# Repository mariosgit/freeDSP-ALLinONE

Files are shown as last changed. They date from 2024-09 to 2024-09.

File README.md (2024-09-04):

# freeDSP ALLinONE
BOARD STATUS: READY TO BE BUILT

Upgrade of the [freeDSP Classic SMD-B](https://github.com/freeDSP/freeDSP-CLASSIC-SMD-B/blob/master/README.md)

LICENCE: Creative Commons Attribution Share-Alike 4.0 license

https://freedsp.github.io/

[Mouser BOM](https://www.mouser.com/ProjectManager/ProjectDetail.aspx?AccessID=5c5f7288d7)

## mb/improvements branch

 * PowerDown muting, implemented with one 7414 gate and a Pot. The Pot must be fully turned up (cw) and then down until the mute LED turns of. This determines the Vin voltage where the shutdown occures, it should be slightly below the supply voltage but higher then 5V because @5V the Amps will go into power fail and that will hard click. [simulation](https://www.falstad.com/circuit/circuitjs.html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)
 * One of the 7414 was redundand and has been removed.
 * One of the clip adjust pots was redundand and has been removed.
 * 5V Arduino port was removed, use a 3.3 V device, i2C on the freedsp and adau headers.
 * Added a MCP23008 to read status and provide mute and spdif switching control. Can be left out.
 * I had problems with the ADAU onboard voltage regulator, replaced it with a linear regulator. (dropout is 1.2V should be ok to run @ 3.3V) Anyway increased the switched reg to 5V and the 3.3V line runs on another 1117.
 * Ferritbead before the AMP chips is wrong, AMPs are now powered by VIN.
 * Removed Power input from USBi port.
 * JumperWire and solder enforceable power traces between amps and power terminal
 * break out gain config pins - add 1k resistors r49 r50 as needed.

##### CanDo ?

 * Replace CS8422 QFPpamp / Outdated. But it's the only one with integrated SRC :( 
 * Replace 1206 parts with std 603 parts.
 * Use a power management/supervisor chipo for mute ? 
   * TPS3840PH49DBVR ? ActHigh not adjustable, max 12v
   * TL7700 - active low
   * TPS38 - availables are active low.
   * TL7733 - max 20V, act low+high
   * aaahhh

## About

The freeDSP is an open-source digital signal processor family for the do-it-yourself community. The applications range from active loudspeaker concepts (digital crossovers, bass enhancement, ...) and room equalization over advanced musical effect processors to car audio signal processing. 

The _freeDSP ALLinONE_ is an all-in-one version of the original _freeDSP Classic SMD-B_ with a few improvements, upgrades and changes.
It features four amplified analog outputs as well as S/PDIF in- and output (optical and RCA).
This board has been designed using the Cross-Platform Open Source Tool [KiCad](http://kicad.org/).

More informations kann be found on the [freeDSP website](http://freedsp.cc)

You can find a PDF version of the schematic in the SOURCES folder (LINK)

## Links

[freeDSP Website](http://freedsp.cc)

[Documentation in Google Doc](https://docs.google.com/document/d/1258PKKEvrk1GpFIaAHhm8G6f0HHNBfSL8KVq2VGgUKc/edit?usp=sharing)

[freeDSP Guidelines](https://github.com/freeDSP/WIKI-AND-GENERAL-TOPICS/wiki/freeDSP-Guidelines)

## Git usage

#### How to setup local repository
- Change to your FreeDSP directory
- Clone the repository (including submodule)  
 `git clone --recursive https://github.com/freeDSP/freeDSP-ALLinONE.git` 
- Change to the newly created ALLinONE directory
- Checkout a branch for the library submodule, if you want to modify it as well
  `git submodule foreach 'git checkout 'master''`
- Open the project file in KiCad

#### How to update the local copy
- To update the project  
  `git pull`
- To update the library  
  `git submodule update --remote --merge`

#### To commit and push local changes
- If you modified something in the LIBRARY folder, change to the LIBRARY folder and run  
  `git add .` (Only required if files were added)  
  `git commit -am "Message"`  (Describe what you changed)  
- Change to the project root directory and run
  `git add .` (Only required if files were added)  
  `git commit -am "Message"`  (Describe what you changed)    
- In the project directory run  
  `git push --recurse-submodule=on-demand`  

#### Define alias to make things shorter
- In the project directory run
  `git config alias.supdate 'submodule update --remote --merge'`  
  `git config alias.spush 'push --recurse-submodules=on-demand'`  
- Afterwards you can use `git supdate` to update the submodule and `git spush` to push any commited changes  

#### Other useful commands
- `git status`  
  Shows general information about the current branch, uncommited changes, not yet added new files and more
- `git diff`  
  Shows uncommited changes
- `git reset --hard origin/master`
  Reset all files to the current status of the dev-hs-01 branch on the Github repository  
  **Careful** This deletes all local changes, so make sure all changes you made and you do not want to delete are pushed to the remote repository

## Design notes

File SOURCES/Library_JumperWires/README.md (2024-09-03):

Found there:
https://forum.kicad.info/t/jumper-wires-for-single-double-sided-pcbs/26446

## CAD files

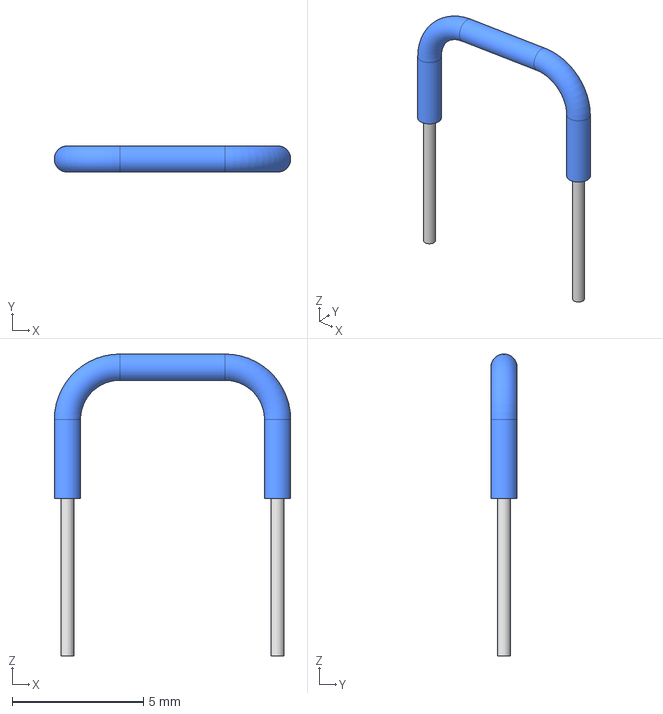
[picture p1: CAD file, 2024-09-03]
SOURCES/Library_JumperWires/Jumper-Wire_8mm_Blue.step
9.00 x 1 x 11.5 mm

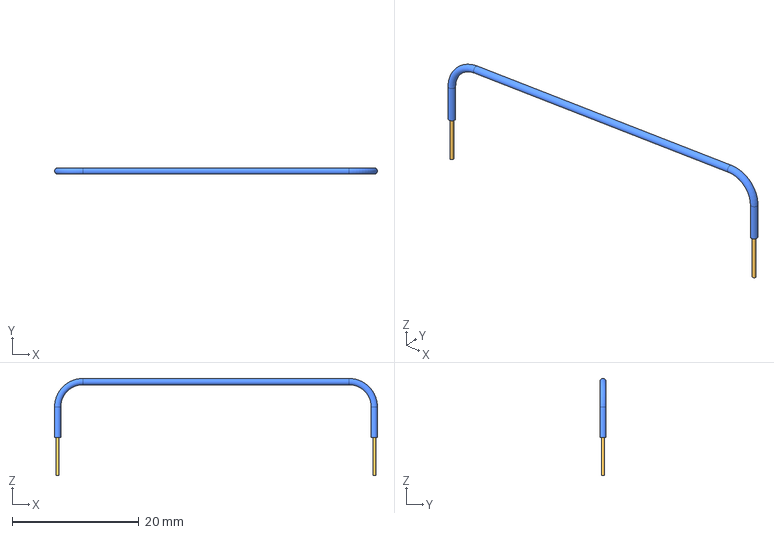
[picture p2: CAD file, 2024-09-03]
SOURCES/Library_JumperWires/Jumper-Wire_50mm_Blue.step
51.0 x 1 x 15.3 mm

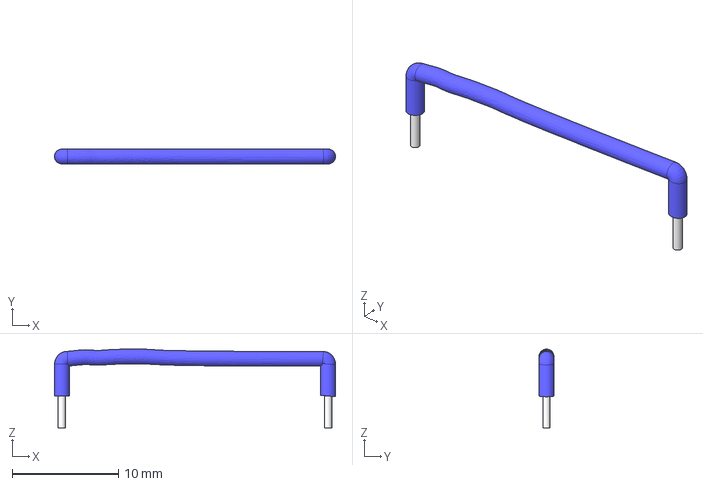
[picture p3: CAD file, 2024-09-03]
SOURCES/Library_JumperWires/Jumper-Wire_25mm_Blue.step
26.4 x 1.40 x 7.41 mm

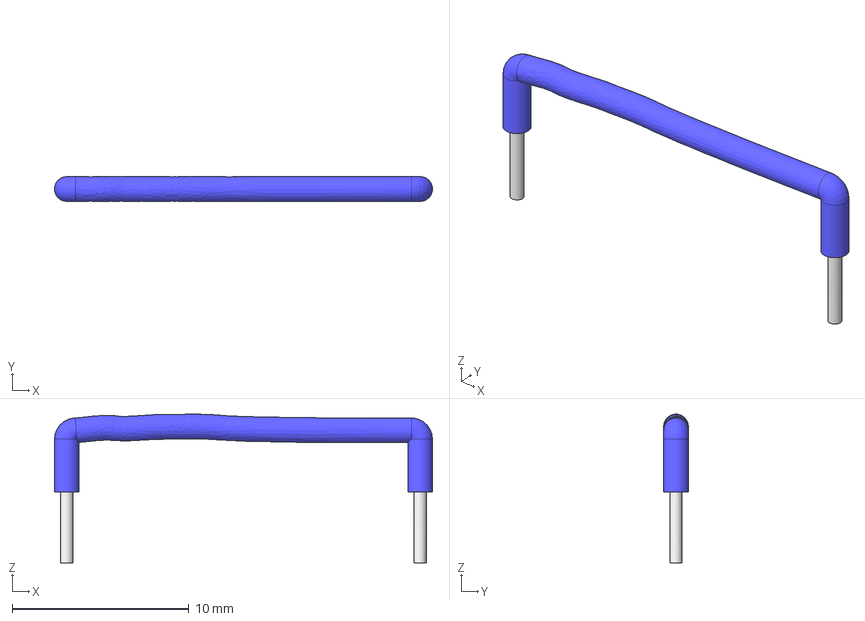
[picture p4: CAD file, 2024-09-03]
SOURCES/Library_JumperWires/Jumper-Wire_20mm_Blue.step
21.4 x 1.40 x 8.41 mm

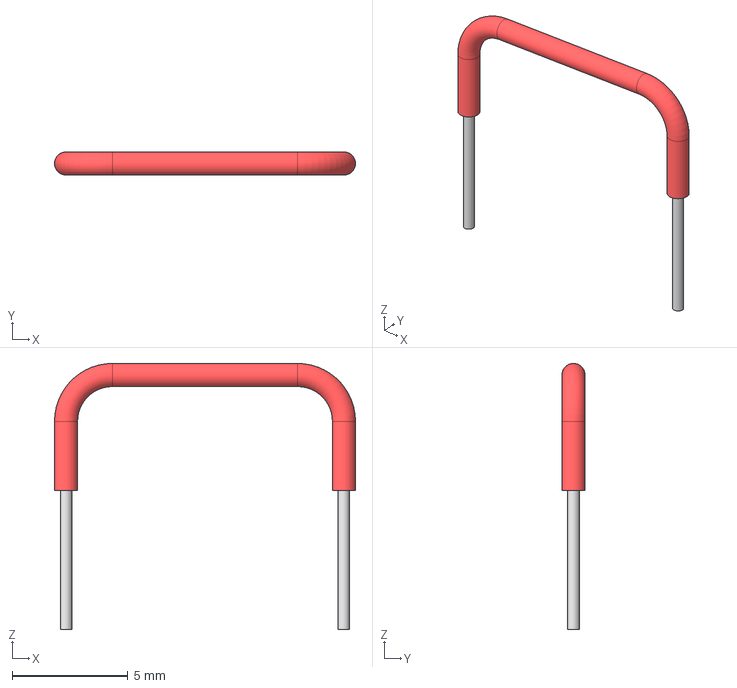
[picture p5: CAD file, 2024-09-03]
SOURCES/Library_JumperWires/Jumper-Wire_12mm_Red.step
13.0 x 1 x 11.5 mm

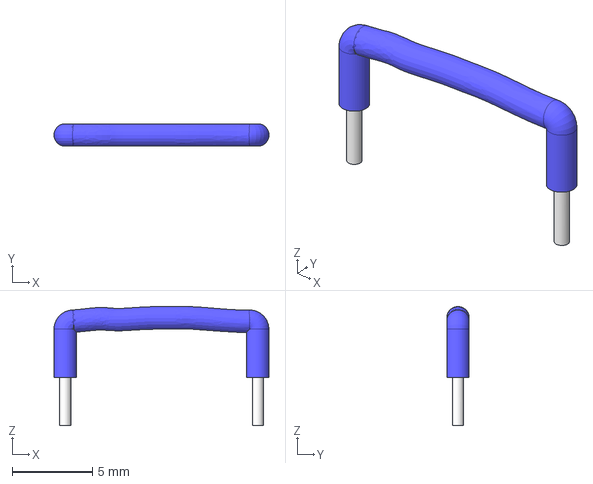
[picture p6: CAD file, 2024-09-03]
SOURCES/Library_JumperWires/Jumper-Wire_12mm_Blue.step
13.4 x 1.40 x 7.42 mm

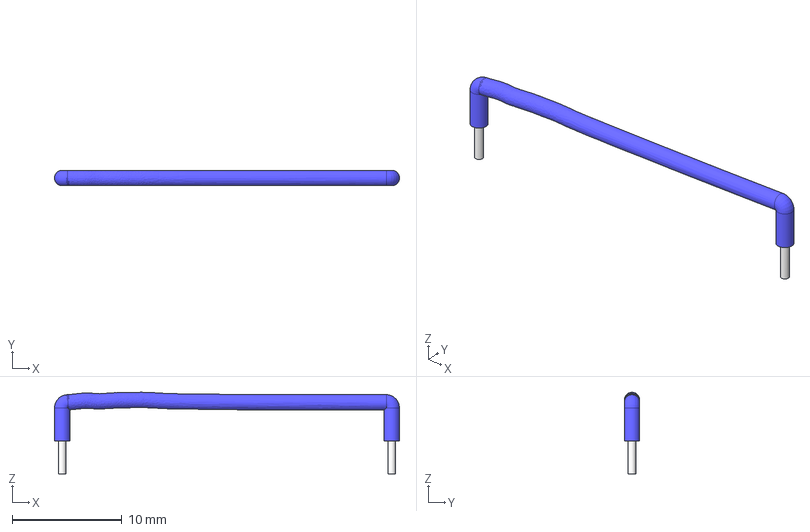
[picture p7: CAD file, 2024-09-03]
SOURCES/Library_JumperWires/Jumper-Wire_30mm_Blue.step
31.4 x 1.40 x 7.42 mm

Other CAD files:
SOURCES/Library_JumperWires/Jumper-Wire_8mm_Red.step

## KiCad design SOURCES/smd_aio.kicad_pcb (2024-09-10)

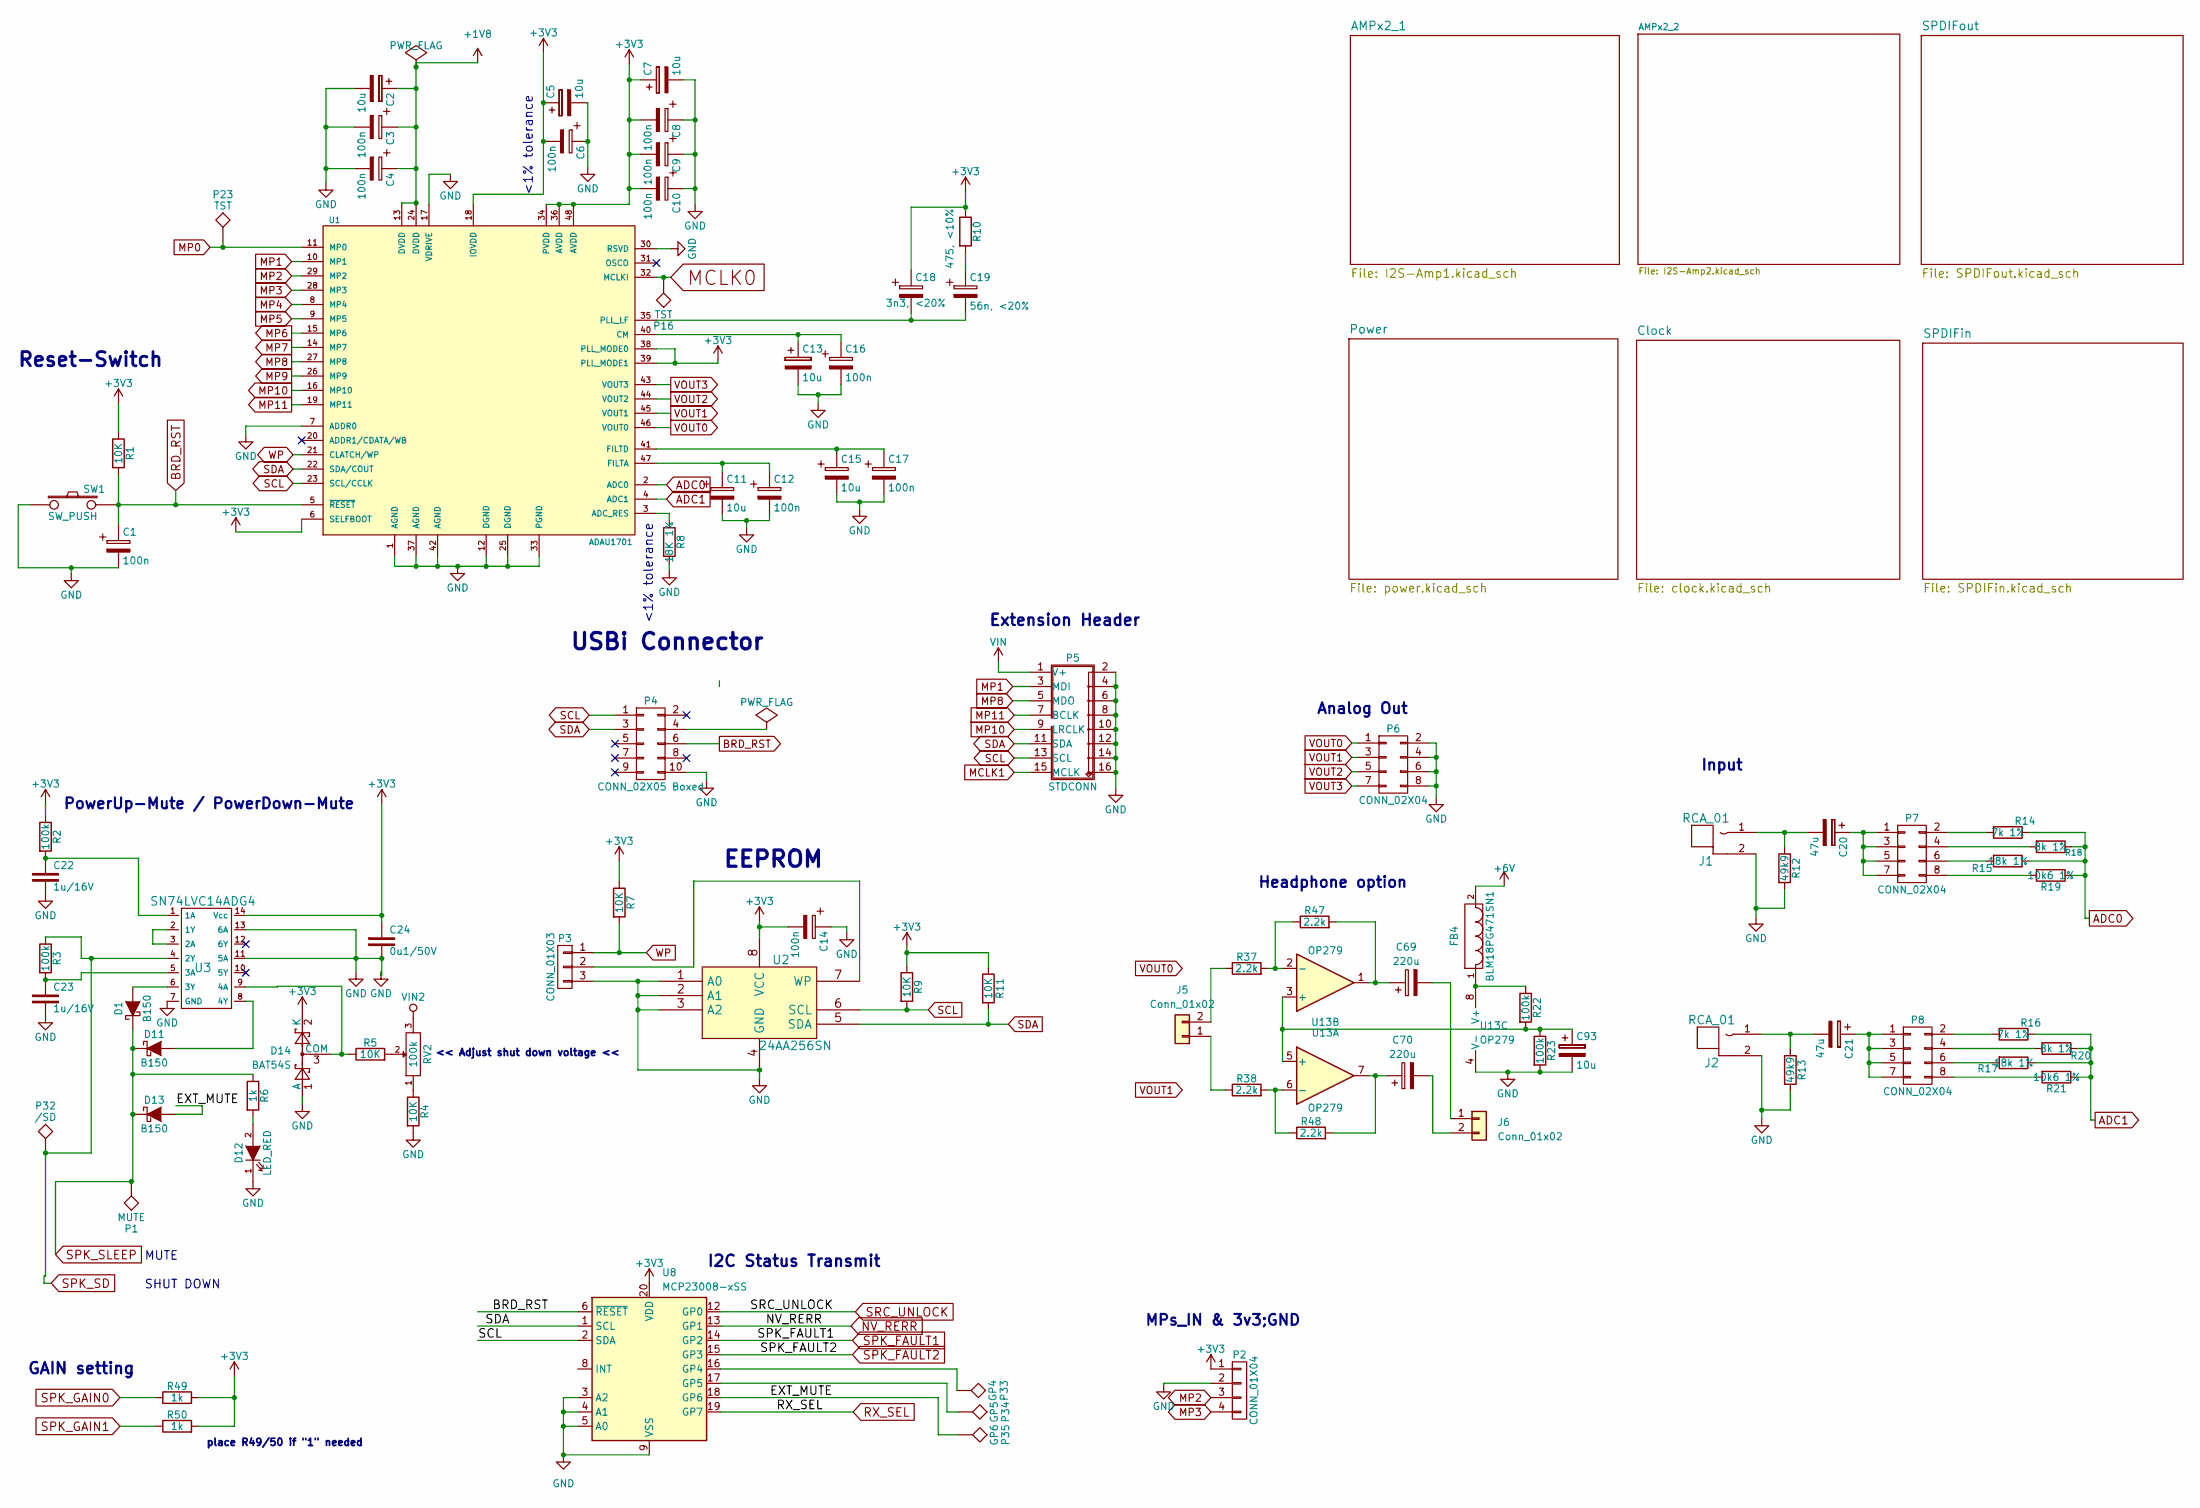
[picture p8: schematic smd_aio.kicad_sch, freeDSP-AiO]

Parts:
C1, C3, C4, C6, C8, C9, C10, C12, C14, C16, C17: 100n; C_1206_HandSoldering
C2: 10u; C_1210_3225Metric_Pad1.33x2.70mm_HandSolder
C5, C7, C13, C93: 10u; C_Radial_D5_L11_P2
C11, C15: 10u; C_1206_HandSoldering
C18: 3n3, <20%; C_1206_HandSoldering
C19: 56n, <20%; C_1206_HandSoldering
C20, C21: 47u; C_Radial_D5_L11_P2
C22, C23: 1u/16V; C_1206_HandSoldering
C24: 0u1/50V; C_1206_HandSoldering
C69, C70: 220u; CP_Elec_6.3x5.9
D1, D11, D13: B150; SMA
D12: LED_RED; R_1206_HandSoldering
D14: BAT54S; SOT-23
FB4: BLM18PG471SN1; R_0603_HandSoldering
J1, J2: RCA_01; RCA_RCJ-01x
J5, J6: Conn_01x02; PinHeader_1x02_P2.54mm_Vertical
P1: MUTE; Measurement_Point_Round-SMD-Pad_Small
P2: CONN_01X04; Pin_Header_Straight_1x04
P3: CONN_01X03; Pin_Header_Straight_1x03
P4: CONN_02X05 Boxed; IDC_Header_Straight_10pins
P5: STDCONN; IDC_Header_Straight_16pins
P6, P7, P8: CONN_02X04; Pin_Header_Straight_2x04
P16, P23: TST; Measurement_Point_Round-SMD-Pad_Small
P32: /SD; Measurement_Point_Round-SMD-Pad_Small
P33: GP4; Measurement_Point_Round-SMD-Pad_Small
P34: GP5; Measurement_Point_Round-SMD-Pad_Small
P35: GP6; Measurement_Point_Round-SMD-Pad_Small
R1, R4, R5, R7, R9, R11: 10K; R_1206_HandSoldering
R2, R3: 100k; R_1206_HandSoldering
R6: 1k; R_1206_HandSoldering
R8: 18K 1%; R_1206_HandSoldering
R10: 475, <10%; R_1206_HandSoldering
R12, R13: 49k9; R_1206_HandSoldering
R14, R16: 7k 1%; R_1206_HandSoldering
R15, R17: 18k 1%; R_1206_HandSoldering
R18, R20: 8k 1%; R_1206_HandSoldering
R19, R21: 10k6 1%; R_1206_HandSoldering
R22, R23: 100k; R_0603_HandSoldering
R37, R38, R47, R48: 2.2k; R_0603_HandSoldering
R49, R50: 1k; R_0603_1608Metric_Pad0.98x0.95mm_HandSolder
RV2: 100k; M64Z104KB40
SW1: SW_PUSH; SW_PUSH_6mm
U1: ADAU1701; LQFP-48_7x7mm_Pitch0.5mm
U2: 24AA256SN; SOIC-8_3.9x4.9mm_Pitch1.27mm
U3: SN74LVC14ADG4; SOIC-14_3.9x8.7mm_Pitch1.27mm
U8: MCP23008-xSS; SSOP-20_5.3x7.2mm_P0.65mm
U13: OP279; SO-8_3.9x4.9mm_P1.27mm

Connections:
+1V8: C2.1, C3.1, C4.1, U1.13 (DVDD), U1.24 (DVDD); also elsewhere on the board
+3V3: C5.1, C6.2, C7.1, C8.2, C9.2, C10.2, C14.2, C18.1, C24.1, D14.2 (K), P2.1, R1.1, R2.1, R7.1, R9.1, R10.1, R11.1, R49.2, R50.2, U1.6 (SELFBOOT), U1.18 (IOVDD), U1.34 (PVDD), U1.36 (AVDD), U1.38 (PLL_MODE0), U1.39 (PLL_MODE1), U1.48 (AVDD), U2.8 (VCC), U3.14 (Vcc), U8.20 (VDD); also elsewhere on the board
+6V: FB4.2; also elsewhere on the board
/EXT_MUTE: D13.2 (A), P35.1, U8.18 (GP6)
ADC0: R14.1, R15.1, R18.1, R19.1, U1.2 (ADC0)
ADC1: R16.1, R17.1, R20.1, R21.1, U1.4 (ADC1)
BRD_RST: C1.1, P4.6, R1.2, SW1.2, U1.5 (~RESET), U8.6 (~RESET); also elsewhere on the board
GND: C1.2, C2.2, C3.2, C4.2, C5.2, C6.1, C7.2, C8.1, C9.1, C10.1, C11.2, C12.2, C13.2, C14.1, C15.2, C16.2, C17.2, C22.2, C23.2, C24.2, C93.2, D12.1 (K), D14.1 (A), J1.2 (GND), J2.2 (GND), P2.2, P3.3, P4.10, P5.2 (GND), P5.4 (GND), P5.6 (GND), P5.8 (GND), P5.10 (GND), P5.12 (GND), P5.14 (GND), P5.16 (GND), P6.2, P6.4, P6.6, P6.8, R4.2, R8.2, R12.2, R13.2, R23.2, SW1.1, U1.1 (AGND), U1.7 (ADDR0), U1.12 (DGND), U1.17 (VDRIVE), U1.25 (DGND), U1.30 (RSVD), U1.33 (PGND), U1.37 (AGND), U1.42 (AGND), U2.1 (A0), U2.2 (A1), U2.3 (A2), U2.4 (GND), U3.7 (GND), U3.11 (5A), U3.13 (6A), U8.3 (A2), U8.4 (A1), U8.5 (A0), U8.9 (VSS), U13.4 (V-); also elsewhere on the board
MCLK0: P16.1, U1.32 (MCLKI); also elsewhere on the board
MCLK1: P5.15 (MCLK); also elsewhere on the board
MP0: P23.1, U1.11 (MP0); also elsewhere on the board
MP1: P5.3 (MDI), U1.10 (MP1)
MP2: P2.3, U1.29 (MP2)
MP3: P2.4, U1.28 (MP3)
MP4: U1.8 (MP4); also elsewhere on the board
MP5: U1.9 (MP5); also elsewhere on the board
MP6: U1.15 (MP6); also elsewhere on the board
MP7: U1.14 (MP7); also elsewhere on the board
MP8: P5.5 (MDO), U1.27 (MP8)
MP9: U1.26 (MP9); also elsewhere on the board
MP10: P5.9 (LRCLK), U1.16 (MP10); also elsewhere on the board
MP11: P5.7 (BCLK), U1.19 (MP11); also elsewhere on the board
NV_RERR: U8.13 (GP1); also elsewhere on the board
unnamed: C19.1, R10.2
unnamed: C69.1, R47.2, U13.1
unnamed: C70.1, R48.2, U13.7
unnamed: D1.2 (A), U3.6 (3Y)
unnamed: D11.2 (A), U3.8 (4Y)
unnamed: D12.2 (A), R6.2
unnamed: D14.3 (COM), R5.1, U3.9 (4A)
unnamed: C20.2, J1.1 (SIG), R12.1
unnamed: C21.2, J2.1 (SIG), R13.1
unnamed: J5.1, R38.1
unnamed: J5.2, R37.1
unnamed: C69.2, J6.1
unnamed: C70.2, J6.2
unnamed: P3.2, U2.7 (WP)
unnamed: C20.1, P7.1, P7.3, P7.5, P7.7
unnamed: P7.2, R14.2
unnamed: P7.4, R18.2
unnamed: P7.6, R15.2
unnamed: P7.8, R19.2
unnamed: C21.1, P8.1, P8.3, P8.5, P8.7
unnamed: P8.2, R16.2
unnamed: P8.4, R20.2
unnamed: P8.6, R17.2
unnamed: P8.8, R21.2
unnamed: R4.1, RV2.1
unnamed: R5.2, RV2.2
unnamed: R8.1, U1.3 (ADC_RES)
unnamed: C13.1, C16.1, U1.40 (CM)
unnamed: C11.1, C12.1, U1.47 (FILTA)
unnamed: C15.1, C17.1, U1.41 (FILTD)
unnamed: C18.2, C19.2, U1.35 (PLL_LF)
unnamed: C22.1, R2.2, U3.1 (1A)
unnamed: U3.2 (1Y), U3.3 (2A)
unnamed: C23.1, R3.2, U3.5 (3A)
unnamed: P33.1, U8.16 (GP4)
unnamed: P34.1, U8.17 (GP5)
unnamed: C93.1, R22.2, R23.1, U13.3 (+), U13.5 (+)
unnamed: R37.2, R47.1, U13.2 (-)
unnamed: R38.2, R48.1, U13.6 (-)
unnamed: FB4.1, R22.1, U13.8 (V+)
RX_SEL: U8.19 (GP7); also elsewhere on the board
SCL: P4.1, P5.13 (SCL), R9.2, U1.23 (SCL/CCLK), U2.6 (SCL), U8.2 (SDA)
SDA: P4.3, P5.11 (SDA), R11.2, U1.22 (SDA/COUT), U2.5 (SDA), U8.1 (SCL)
SPK_FAULT1: U8.14 (GP2); also elsewhere on the board
SPK_FAULT2: U8.15 (GP3); also elsewhere on the board
SPK_GAIN0: R49.1; also elsewhere on the board
SPK_GAIN1: R50.1; also elsewhere on the board
SPK_SD: P32.1, R3.1, U3.4 (2Y); also elsewhere on the board
SPK_SLEEP: D1.1 (K), D11.1 (K), D13.1 (K), P1.1, R6.1; also elsewhere on the board
SRC_UNLOCK: U8.12 (GP0); also elsewhere on the board
VIN: P5.1 (V+); also elsewhere on the board
VIN2: RV2.3; also elsewhere on the board
VOUT0: P6.1, U1.46 (VOUT0)
VOUT1: P6.3, U1.45 (VOUT1)
VOUT2: P6.5, U1.44 (VOUT2)
VOUT3: P6.7, U1.43 (VOUT3)
WP: P3.1, R7.2, U1.21 (CLATCH/WP)

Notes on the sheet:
MPs_IN & 3v3;GND
Headphone option
PowerUp-Mute / PowerDown-Mute
I2C Status Transmit
MUTE
Extension Header
Analog Out
USBi Connector
place R49/50 if "1" needed
GAIN setting
<< Adjust shut down voltage <<
SHUT DOWN
Reset-Switch
Input
<1% tolerance
EEPROM

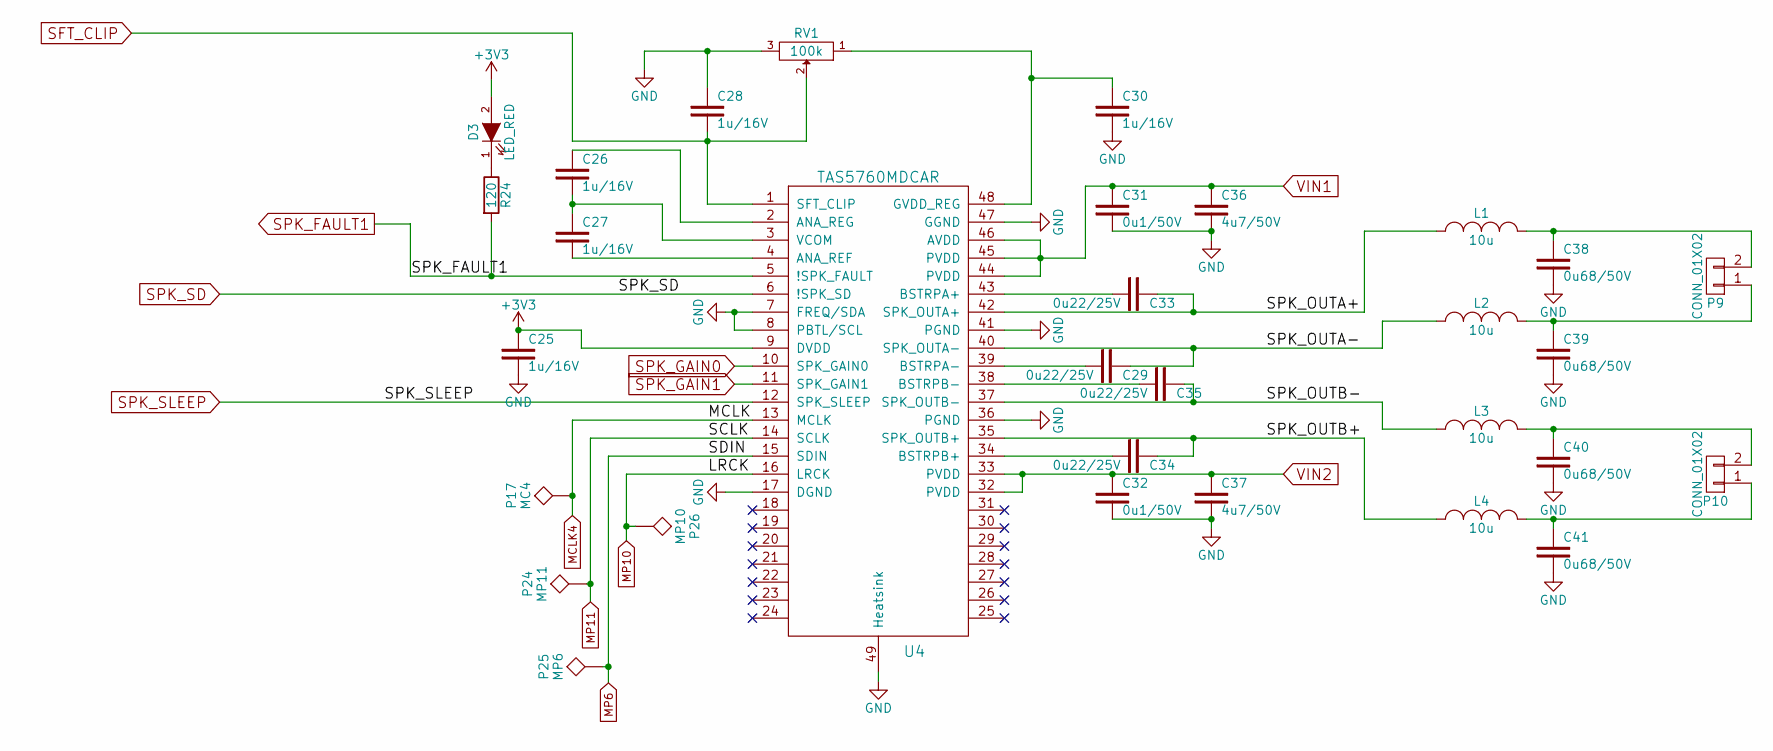
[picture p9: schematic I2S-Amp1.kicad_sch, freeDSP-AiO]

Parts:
C25, C26, C27, C28, C30: 1u/16V; C_1206_HandSoldering
C29, C33, C34, C35: 0u22/25V; C_0805_HandSoldering
C31, C32: 0u1/50V; C_1206_HandSoldering
C36, C37: 4u7/50V; C_1206_HandSoldering
C38, C39, C40, C41: 0u68/50V; C_1206_HandSoldering
D3: LED_RED; R_1206_HandSoldering
L1, L2, L3, L4: 10u; 1D10ASeries
P9, P10: CONN_01X02; RIACON101-2
P17: MC4; Measurement_Point_Round-SMD-Pad_Small
P24: MP11; Measurement_Point_Round-SMD-Pad_Small
P25: MP6; Measurement_Point_Round-SMD-Pad_Small
P26: MP10; Measurement_Point_Round-SMD-Pad_Small
R24: 120; R_1206_HandSoldering
RV1: 100k; M64Z104KB40
U4: TAS5760MDCAR; HTSSOP-48

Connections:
+3V3: C25.1, D3.2 (A), U4.9 (DVDD); also elsewhere on the board
/AMPx2_1/SPK_OUTA+: C33.1, L1.1, U4.42 (SPK_OUTA+)
/AMPx2_1/SPK_OUTA-: C29.1, L2.1, U4.40 (SPK_OUTA-)
/AMPx2_1/SPK_OUTB+: C34.1, L4.1, U4.35 (SPK_OUTB+)
/AMPx2_1/SPK_OUTB-: C35.1, L3.1, U4.37 (SPK_OUTB-)
GND: C25.2, C28.1, C30.2, C31.2, C32.2, C36.2, C37.2, C38.2, C39.2, C40.2, C41.2, RV1.3, U4.7 (FREQ/SDA), U4.8 (PBTL/SCL), U4.17 (DGND), U4.36 (PGND), U4.41 (PGND), U4.47 (GGND), U4.49 (Heatsink); also elsewhere on the board
MCLK4: P17.1, U4.13 (MCLK); also elsewhere on the board
MP6: P25.1, U4.15 (SDIN); also elsewhere on the board
MP10: P26.1, U4.16 (LRCK); also elsewhere on the board
MP11: P24.1, U4.14 (SCLK); also elsewhere on the board
unnamed: D3.1 (K), R24.1
unnamed: C39.1, L2.2, P9.1
unnamed: C38.1, L1.2, P9.2
unnamed: C41.1, L4.2, P10.1
unnamed: C40.1, L3.2, P10.2
unnamed: C27.2, U4.4 (ANA_REF)
unnamed: C26.1, U4.2 (ANA_REG)
unnamed: C33.2, U4.43 (BSTRPA+)
unnamed: C29.2, U4.39 (BSTRPA-)
unnamed: C34.2, U4.34 (BSTRPB+)
unnamed: C35.2, U4.38 (BSTRPB-)
unnamed: C30.1, RV1.1, U4.48 (GVDD_REG)
unnamed: C26.2, C27.1, U4.3 (VCOM)
SFT_CLIP: C28.2, RV1.2, U4.1 (SFT_CLIP); also elsewhere on the board
SPK_FAULT1: R24.2, U4.5 (!SPK_FAULT); also elsewhere on the board
SPK_GAIN0: U4.10 (SPK_GAIN0); also elsewhere on the board
SPK_GAIN1: U4.11 (SPK_GAIN1); also elsewhere on the board
SPK_SD: U4.6 (!SPK_SD); also elsewhere on the board
SPK_SLEEP: U4.12 (SPK_SLEEP); also elsewhere on the board
VIN1: C31.1, C36.1, U4.44 (PVDD), U4.45 (PVDD), U4.46 (AVDD); also elsewhere on the board
VIN2: C32.1, C37.1, U4.32 (PVDD), U4.33 (PVDD); also elsewhere on the board

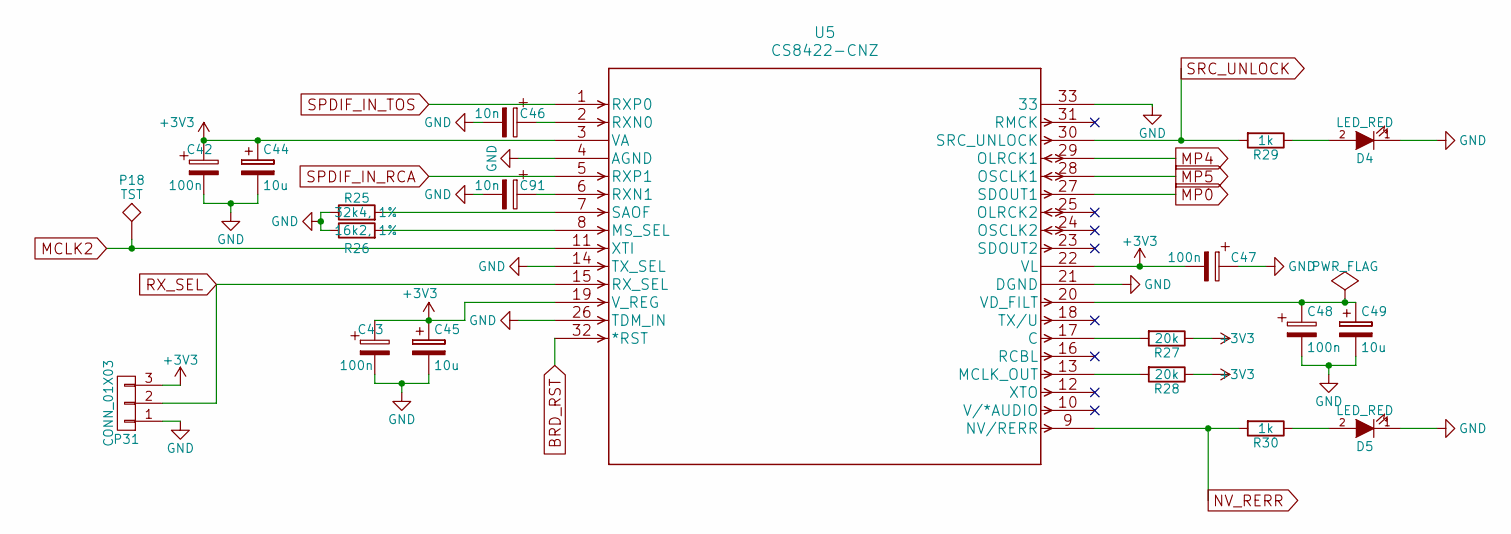
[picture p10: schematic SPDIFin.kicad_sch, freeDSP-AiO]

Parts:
C42, C43, C47, C48: 100n; C_1206_HandSoldering
C44, C45, C49: 10u; C_Radial_D5_L11_P2
C46, C91: 10n; C_1206_HandSoldering
D4, D5: LED_RED; R_1206_HandSoldering
P18: TST; Measurement_Point_Round-SMD-Pad_Small
P31: CONN_01X03; Pin_Header_Straight_1x03
R25: 32k4, 1%; R_1206_HandSoldering
R26: 16k2, 1%; R_1206_HandSoldering
R27, R28: 20k; R_1206_HandSoldering
R29, R30: 1k; R_1206_HandSoldering
U5: CS8422-CNZ

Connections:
+3V3: C42.1, C43.1, C44.1, C45.1, C47.2, P31.3, R27.1, R28.1, U5.3 (VA), U5.19 (V_REG), U5.22 (VL); also elsewhere on the board
BRD_RST: U5.32 (*RST); also elsewhere on the board
GND: C42.2, C43.2, C44.2, C45.2, C46.2, C47.1, C48.2, C49.2, C91.2, D4.1 (K), D5.1 (K), P31.1, R25.1, R26.1, U5.4 (AGND), U5.14 (TX_SEL), U5.21 (DGND), U5.26 (TDM_IN), U5.33; also elsewhere on the board
MCLK2: P18.1, U5.11 (XTI); also elsewhere on the board
MP0: U5.27 (SDOUT1); also elsewhere on the board
MP4: U5.29 (OLRCK1); also elsewhere on the board
MP5: U5.28 (OSCLK1); also elsewhere on the board
NV_RERR: R30.2, U5.9 (NV/RERR); also elsewhere on the board
unnamed: D4.2 (A), R29.1
unnamed: D5.2 (A), R30.1
unnamed: R27.2, U5.17 (C)
unnamed: R28.2, U5.13 (MCLK_OUT)
unnamed: R26.2, U5.8 (MS_SEL)
unnamed: C46.1, U5.2 (RXN0)
unnamed: C91.1, U5.6 (RXN1)
unnamed: R25.2, U5.7 (SAOF)
unnamed: C48.1, C49.1, U5.20 (VD_FILT)
RX_SEL: P31.2, U5.15 (RX_SEL); also elsewhere on the board
SPDIF_IN_RCA: U5.5 (RXP1); also elsewhere on the board
SPDIF_IN_TOS: U5.1 (RXP0); also elsewhere on the board
SRC_UNLOCK: R29.2, U5.30 (SRC_UNLOCK); also elsewhere on the board

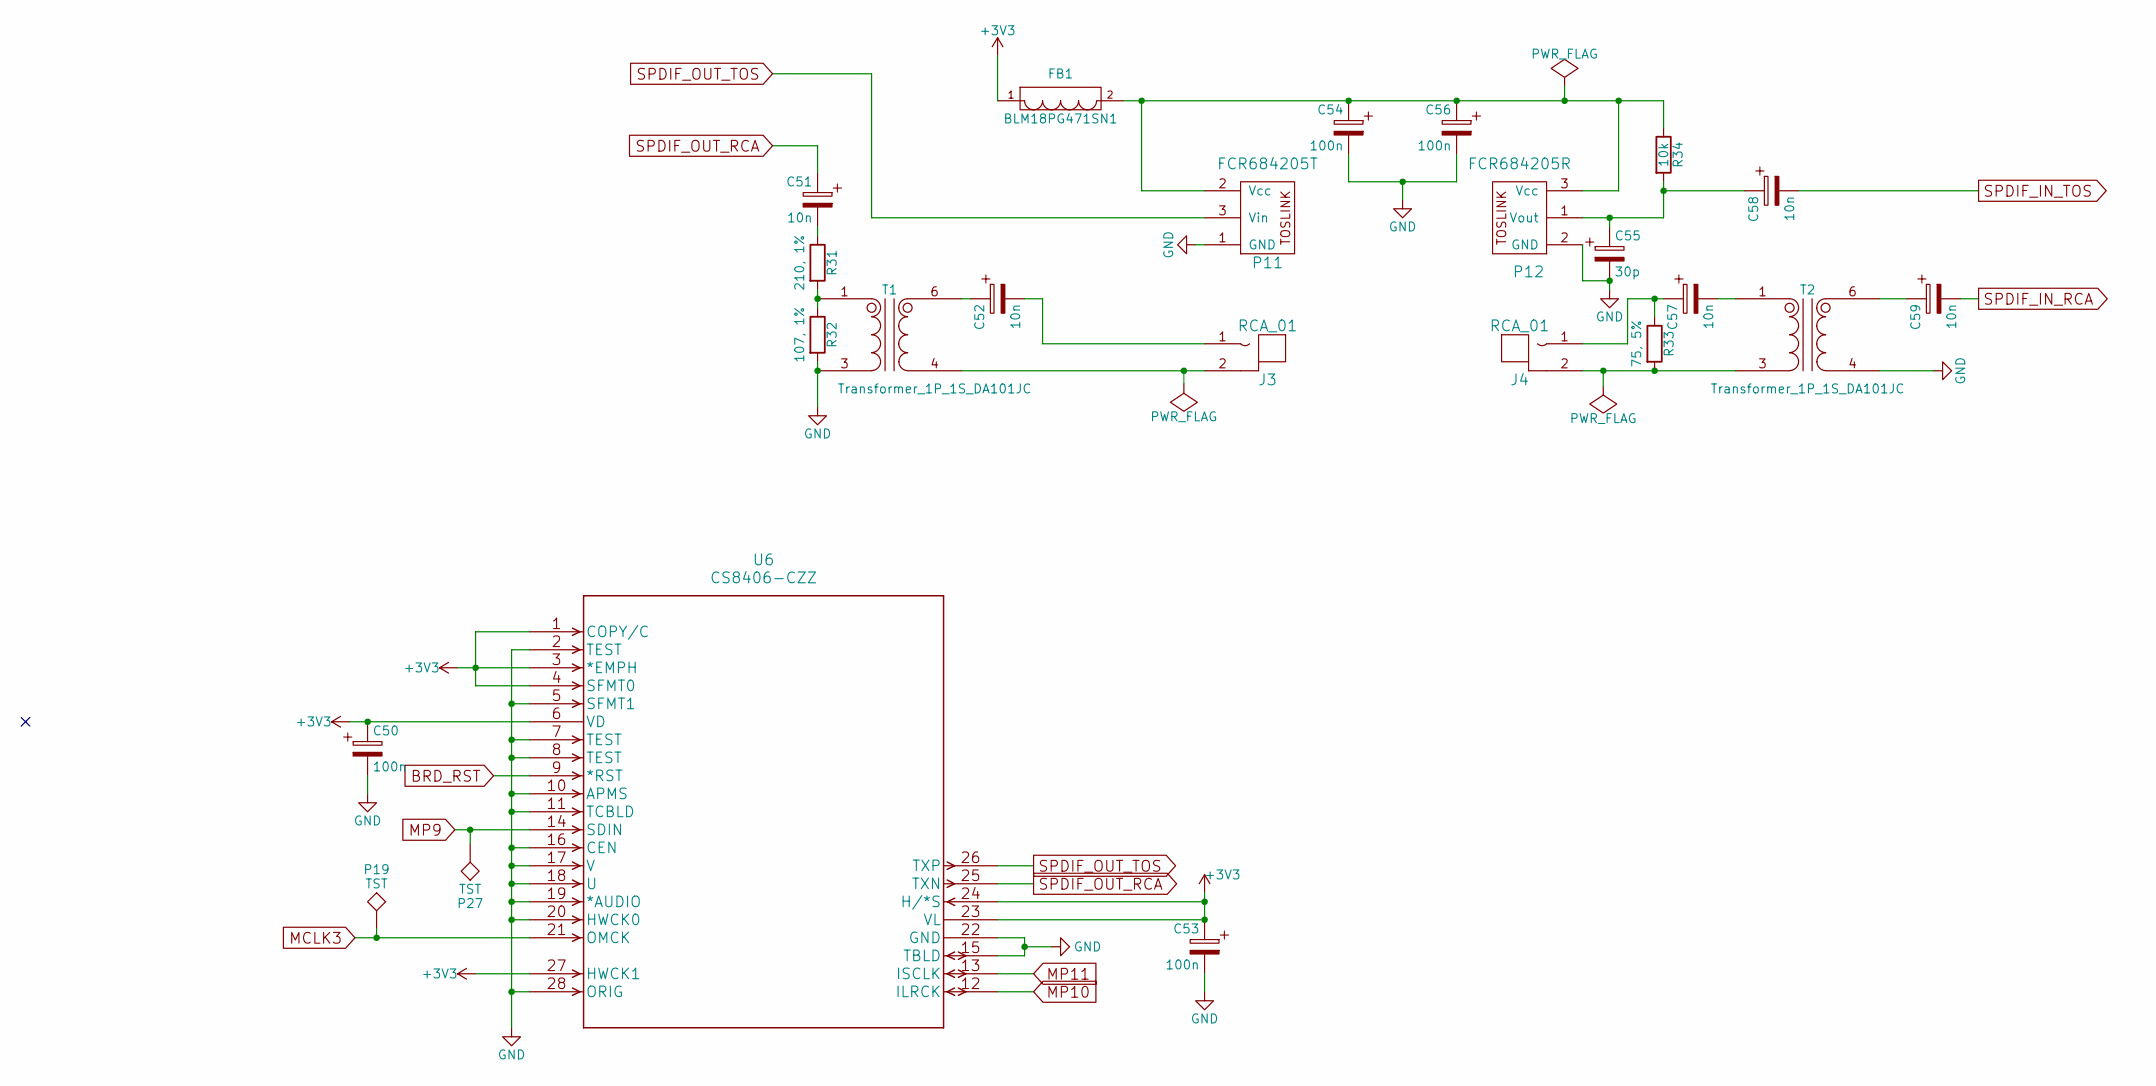
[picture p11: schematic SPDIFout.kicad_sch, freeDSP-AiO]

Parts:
C50, C53, C54, C56: 100n; C_1206_HandSoldering
C51, C52, C57, C58, C59: 10n; C_1206_HandSoldering
C55: 30p; C_1206_HandSoldering
FB1: BLM18PG471SN1; R_0603_HandSoldering
J3, J4: RCA_01; RCA_RCJ-01x
P11: FCR684205T; FC684205_R_T
P12: FCR684205R; FC684205_R_T
P19, P27: TST; Measurement_Point_Round-SMD-Pad_Small
R31: 210, 1%; R_1206_HandSoldering
R32: 107, 1%; R_1206_HandSoldering
R33: 75, 5%; R_1206_HandSoldering
R34: 10k; R_1206_HandSoldering
T1, T2: Transformer_1P_1S_DA101JC; DA101JC
U6: CS8406-CZZ

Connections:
+3V3: C50.1, C53.1, FB1.1, U6.1 (COPY/C), U6.3 (*EMPH), U6.4 (SFMT0), U6.6 (VD), U6.23 (VL), U6.24 (H/*S), U6.27 (HWCK1); also elsewhere on the board
BRD_RST: U6.9 (*RST); also elsewhere on the board
GND: C50.2, C53.2, C54.2, C55.2, C56.2, P11.1 (GND), P12.2 (GND), R32.2, T1.3 (SM), T2.4 (S1), U6.2 (TEST), U6.5 (SFMT1), U6.7 (TEST), U6.8 (TEST), U6.10 (APMS), U6.11 (TCBLD), U6.15 (TBLD), U6.16 (CEN), U6.17 (V), U6.18 (U), U6.19 (*AUDIO), U6.20 (HWCK0), U6.22 (GND), U6.28 (ORIG); also elsewhere on the board
MCLK3: P19.1, U6.21 (OMCK); also elsewhere on the board
MP9: P27.1, U6.14 (SDIN); also elsewhere on the board
MP10: U6.12 (ILRCK); also elsewhere on the board
MP11: U6.13 (ISCLK); also elsewhere on the board
unnamed: C51.2, R31.1
unnamed: J3.2 (GND), T1.4 (S1)
unnamed: C52.2, J3.1 (SIG)
unnamed: J4.2 (GND), R33.2, T2.3 (SM)
unnamed: C57.1, J4.1 (SIG), R33.1
unnamed: C54.1, C56.1, FB1.2, P11.2 (Vcc), P12.3 (Vcc), R34.1
unnamed: C55.1, C58.1, P12.1 (Vout), R34.2
unnamed: C52.1, T1.6 (PM)
unnamed: R31.2, R32.1, T1.1 (PR1)
unnamed: C59.1, T2.6 (PM)
unnamed: C57.2, T2.1 (PR1)
SPDIF_IN_RCA: C59.2; also elsewhere on the board
SPDIF_IN_TOS: C58.2; also elsewhere on the board
SPDIF_OUT_RCA: C51.1, U6.25 (TXN)
SPDIF_OUT_TOS: P11.3 (Vin), U6.26 (TXP)

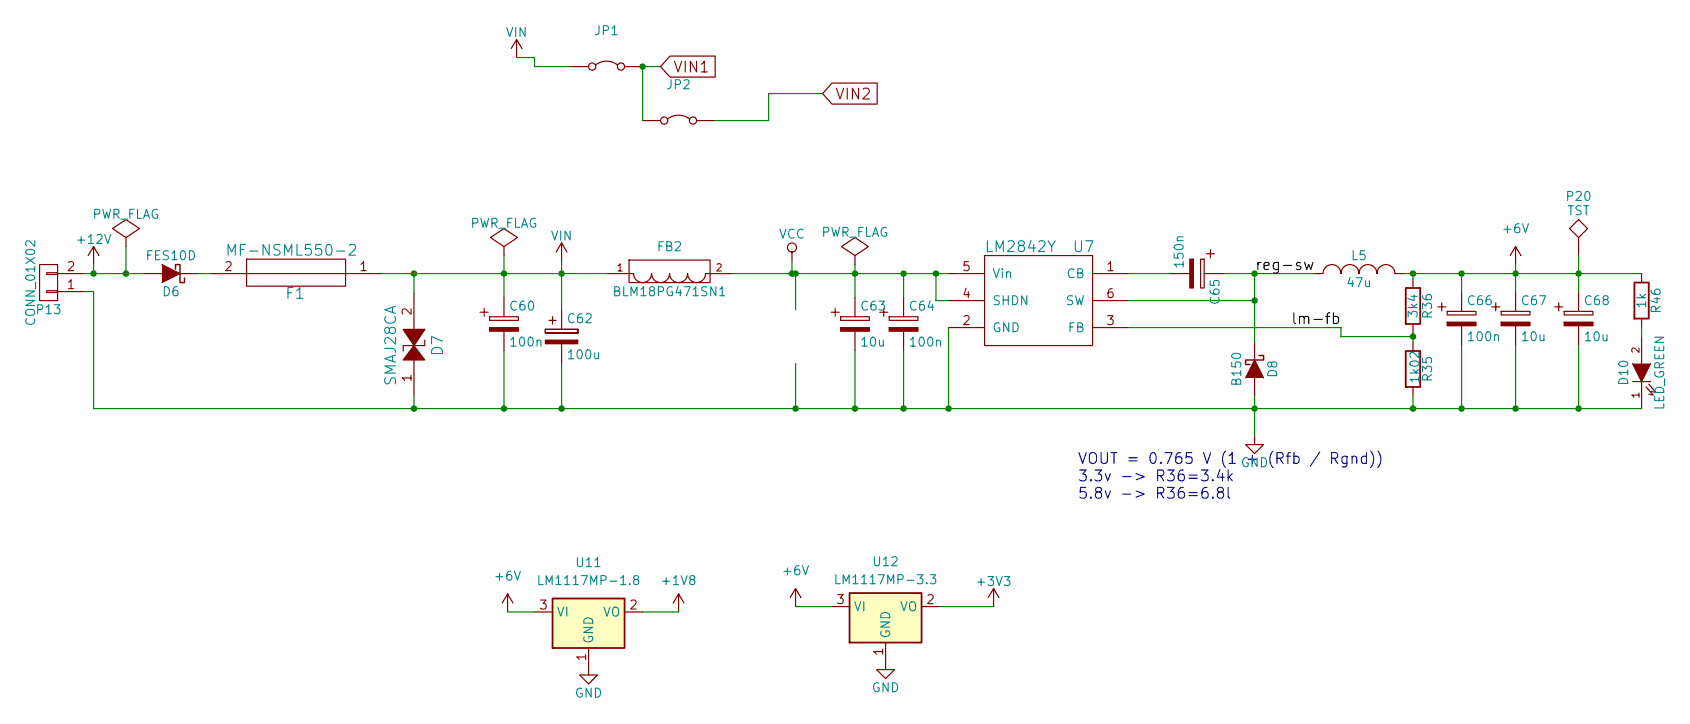
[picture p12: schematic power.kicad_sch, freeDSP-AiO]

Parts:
C60, C64, C66: 100n; C_1206_HandSoldering
C62: 100u; C_Radial_D6.3_L11.2_P2.5
C63, C67, C68: 10u; C_1206_HandSoldering
C65: 150n; C_1206_HandSoldering
D6: FES10D
D7: SMAJ28CA; SMA
D8: B150; SMA
D10: LED_GREEN; R_1206_HandSoldering
F1: MF-NSML550-2; R_1206_HandSoldering
FB2: BLM18PG471SN1; R_0603_HandSoldering
JP1, JP2: Jumper_2_Bridged; Jumper-Wire_25mm_Blue
L5: 47u; Choke_SMD_10.1x10.0
P13: CONN_01X02; RIACON101-2
P20: TST; Measurement_Point_Round-SMD-Pad_Small
R35: 1k02; R_1206_HandSoldering
R36: 3k4; R_1206_HandSoldering
R46: 1k; R_1206_HandSoldering
U7: LM2842Y; SOT23-6_1.7x3.0mm_Pitch0.95mm
U11: LM1117MP-1.8; SOT-223-3_TabPin2
U12: LM1117MP-3.3; SOT-223-3_TabPin2

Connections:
+1V8: U11.2 (VO); also elsewhere on the board
+3V3: U12.2 (VO); also elsewhere on the board
+6V: C66.1, C67.1, C68.1, L5.2, P20.1, R36.1, R46.1, U11.3 (VI), U12.3 (VI); also elsewhere on the board
+12V: D6.2 (A), P13.2
/Power/lm-fb: R35.1, R36.2, U7.3 (FB)
/Power/reg-sw: C65.1, D8.1 (K), L5.1, U7.6 (SW)
GND: C60.2, C62.2, C63.2, C64.2, C66.2, C67.2, C68.2, D7.1, D8.2 (A), D10.1 (K), P13.1, R35.2, U7.2 (GND), U11.1 (GND), U12.1 (GND); also elsewhere on the board
unnamed: D6.1 (K), F1.2
unnamed: D10.2 (A), R46.2
unnamed: C65.2, U7.1 (CB)
VCC: C63.1, C64.1, FB2.2, U7.4 (SHDN), U7.5 (Vin)
VIN: C60.1, C62.1, D7.2, F1.1, FB2.1, JP1.1 (A); also elsewhere on the board
VIN1: JP1.2 (B), JP2.1 (A); also elsewhere on the board
VIN2: JP2.2 (B); also elsewhere on the board

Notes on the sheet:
VOUT = 0.765 V (1 + (Rfb / Rgnd)) 3.3v -> R36=3.4k 5.8v -> R36=6.8l

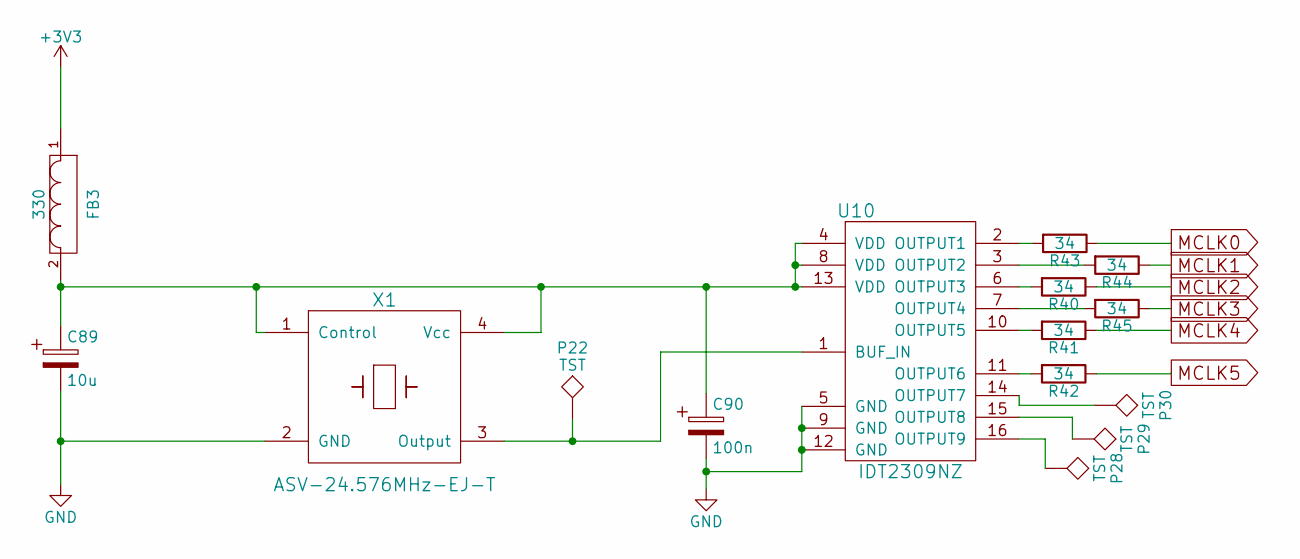
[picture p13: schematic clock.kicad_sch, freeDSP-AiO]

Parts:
C89: 10u; C_1206_HandSoldering
C90: 100n; C_1206_HandSoldering
FB3: 330; C_0805_HandSoldering
P22, P28, P29, P30: TST; Measurement_Point_Round-SMD-Pad_Small
R40, R41, R42, R43, R44, R45: 34; R_1206_HandSoldering
U10: IDT2309NZ; SOIC-16_3.9x9.9mm_Pitch1.27mm
X1: ASV-24.576MHz-EJ-T; Oscillator_SMD_Abracon_ASV-4pin_7.0x5.1mm_HandSoldering

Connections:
+3V3: FB3.1; also elsewhere on the board
GND: C89.2, C90.2, U10.5 (GND), U10.9 (GND), U10.12 (GND), X1.2 (GND); also elsewhere on the board
MCLK0: R43.1; also elsewhere on the board
MCLK1: R44.1; also elsewhere on the board
MCLK2: R40.1; also elsewhere on the board
MCLK3: R45.1; also elsewhere on the board
MCLK4: R41.1; also elsewhere on the board
MCLK5: R42.1; also elsewhere on the board
unnamed: P22.1, U10.1 (BUF_IN), X1.3 (Output)
unnamed: R43.2, U10.2 (OUTPUT1)
unnamed: R44.2, U10.3 (OUTPUT2)
unnamed: R40.2, U10.6 (OUTPUT3)
unnamed: R45.2, U10.7 (OUTPUT4)
unnamed: R41.2, U10.10 (OUTPUT5)
unnamed: R42.2, U10.11 (OUTPUT6)
unnamed: P30.1, U10.14 (OUTPUT7)
unnamed: P29.1, U10.15 (OUTPUT8)
unnamed: P28.1, U10.16 (OUTPUT9)
unnamed: C89.1, C90.1, FB3.2, U10.4 (VDD), U10.8 (VDD), U10.13 (VDD), X1.1 (Control), X1.4 (Vcc)

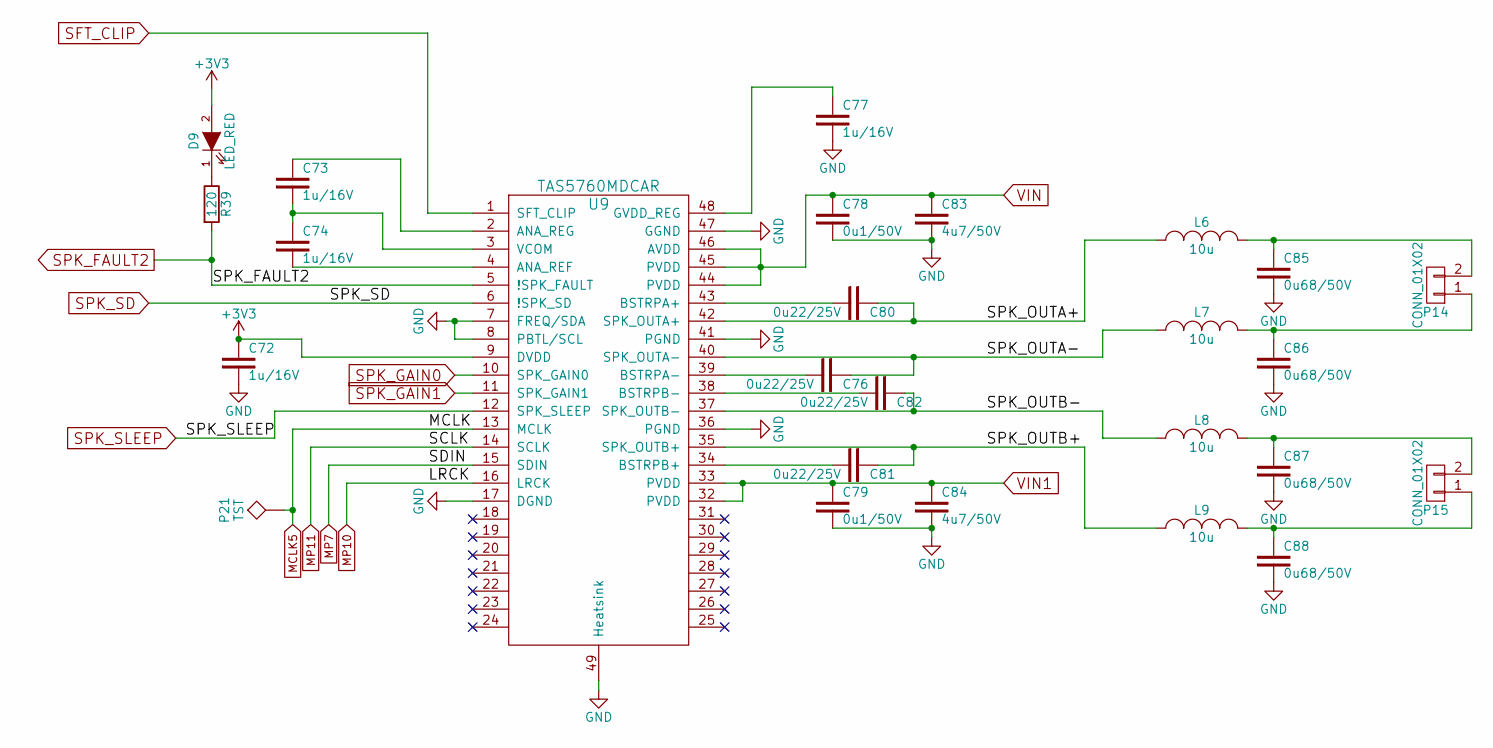
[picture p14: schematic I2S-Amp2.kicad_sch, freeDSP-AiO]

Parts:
C72, C73, C74, C77: 1u/16V; C_1206_HandSoldering
C76, C80, C81, C82: 0u22/25V; C_0805_HandSoldering
C78, C79: 0u1/50V; C_1206_HandSoldering
C83, C84: 4u7/50V; C_1206_HandSoldering
C85, C86, C87, C88: 0u68/50V; C_1206_HandSoldering
D9: LED_RED; R_1206_HandSoldering
L6, L7, L8, L9: 10u; 1D10ASeries
P14, P15: CONN_01X02; RIACON101-2
P21: TST; Measurement_Point_Round-SMD-Pad_Small
R39: 120; R_1206_HandSoldering
U9: TAS5760MDCAR; HTSSOP-48

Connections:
+3V3: C72.1, D9.2 (A), U9.9 (DVDD); also elsewhere on the board
/AMPx2_2/SPK_OUTA+: C80.1, L6.1, U9.42 (SPK_OUTA+)
/AMPx2_2/SPK_OUTA-: C76.1, L7.1, U9.40 (SPK_OUTA-)
/AMPx2_2/SPK_OUTB+: C81.1, L9.1, U9.35 (SPK_OUTB+)
/AMPx2_2/SPK_OUTB-: C82.1, L8.1, U9.37 (SPK_OUTB-)
GND: C72.2, C77.2, C78.2, C79.2, C83.2, C84.2, C85.2, C86.2, C87.2, C88.2, U9.7 (FREQ/SDA), U9.8 (PBTL/SCL), U9.17 (DGND), U9.36 (PGND), U9.41 (PGND), U9.47 (GGND), U9.49 (Heatsink); also elsewhere on the board
MCLK5: P21.1, U9.13 (MCLK); also elsewhere on the board
MP7: U9.15 (SDIN); also elsewhere on the board
MP10: U9.16 (LRCK); also elsewhere on the board
MP11: U9.14 (SCLK); also elsewhere on the board
unnamed: D9.1 (K), R39.1
unnamed: C86.1, L7.2, P14.1
unnamed: C85.1, L6.2, P14.2
unnamed: C88.1, L9.2, P15.1
unnamed: C87.1, L8.2, P15.2
unnamed: C74.2, U9.4 (ANA_REF)
unnamed: C73.1, U9.2 (ANA_REG)
unnamed: C80.2, U9.43 (BSTRPA+)
unnamed: C76.2, U9.39 (BSTRPA-)
unnamed: C81.2, U9.34 (BSTRPB+)
unnamed: C82.2, U9.38 (BSTRPB-)
unnamed: C77.1, U9.48 (GVDD_REG)
unnamed: C73.2, C74.1, U9.3 (VCOM)
SFT_CLIP: U9.1 (SFT_CLIP); also elsewhere on the board
SPK_FAULT2: R39.2, U9.5 (!SPK_FAULT); also elsewhere on the board
SPK_GAIN0: U9.10 (SPK_GAIN0); also elsewhere on the board
SPK_GAIN1: U9.11 (SPK_GAIN1); also elsewhere on the board
SPK_SD: U9.6 (!SPK_SD); also elsewhere on the board
SPK_SLEEP: U9.12 (SPK_SLEEP); also elsewhere on the board
VIN: C78.1, C83.1, U9.44 (PVDD), U9.45 (PVDD), U9.46 (AVDD); also elsewhere on the board
VIN1: C79.1, C84.1, U9.32 (PVDD), U9.33 (PVDD); also elsewhere on the board

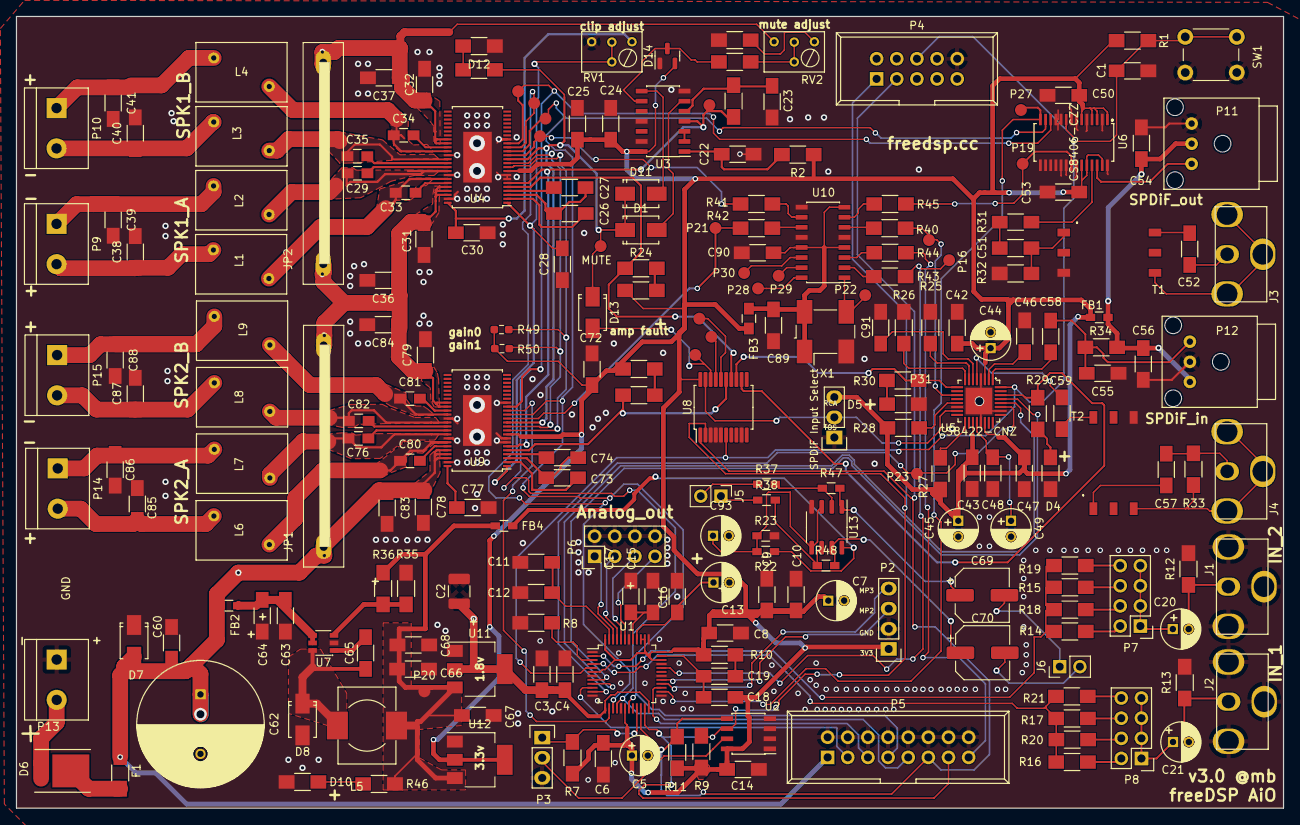
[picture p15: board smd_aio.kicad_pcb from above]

Board: 2 copper layers, 159.8 x 99.8 mm, 228 parts (0 on the bottom side), 162 nets.

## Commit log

2024-01-24 Converted to KiCad7
    [I2S-Amp1-2024-01-24-15-16-59.sch, I2S-Amp1.kicad_sch, I2S-Amp2-2024-01-24-15-16-59.sch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]
2024-01-24 DRC checked.
    [I2S-Amp1.kicad_sch, I2S-Amp2.kicad_sch, SPDIFin.kicad_sch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]
2024-01-24 Removed redundant 7414 and pot, rerouted a bit.
    [I2S-Amp1.kicad_sch, I2S-Amp2.kicad_sch, SPDIFout.kicad_sch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]
2024-01-25 Removed ArduinoPort, Changed Power Supply. Rerouting and stuff.
    [I2S-Amp1.kicad_sch, I2S-Amp2.kicad_sch, SPDIFin.kicad_sch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]
2024-01-26 Added power down detection.
    [I2S-Amp1.kicad_sch, smd_aio.kicad_pcb, smd_aio.kicad_sch]
2024-01-29 Moved input cap and Reset btn.
    [smd_aio-B.Cu.gbl, smd_aio-B.Mask.gbs, smd_aio-B.SilkS.gbo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]
2024-01-30 Added mute adjust, improved layout.
    [I2S-Amp1.kicad_sch, power.kicad_sch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]
2024-01-31 Removed old files.
    [I2S-Amp1.sch, I2S-Amp2.sch, SPDIFin.sch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]
2024-01-31 Optimized Vreg traces.
    [power.kicad_sch, smd_aio.kicad_pcb]
2024-03-27 Added HP amp
    [smd_aio.kicad_pcb, smd_aio.kicad_sch]
2024-03-31 Added BAT54s OV protect.
    [smd_aio.kicad_pcb, smd_aio.kicad_sch]
2024-08-24 Cleaned up ground plane under amps.
    [I2S-Amp1.kicad_sch, I2S-Amp2.kicad_sch, SPDIFin.kicad_sch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]
2024-09-02 Fixed Vin/Vcc issue.
    [I2S-Amp1.kicad_sch, I2S-Amp2.kicad_sch, power.kicad_sch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]
2024-09-03 Improved power traces.
    [I2S-Amp1.kicad_sch, I2S-Amp2.kicad_sch, Jumper-Wire_12mm_Blue.step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]
2024-09-10 Minor improvents
    [smd_aio.kicad_pcb]
2024-09-10 Made some space for under side heat sink.. todo, move the WP jumper.
    [smd_aio.kicad_pcb, smd_aio.kicad_sch]

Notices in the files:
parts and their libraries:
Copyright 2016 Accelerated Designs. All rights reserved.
